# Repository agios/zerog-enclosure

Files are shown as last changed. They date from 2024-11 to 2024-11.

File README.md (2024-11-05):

# Parametric OpenSCAD enclosure for ZeroG Mercury One.1

<div align="center">
  <a href="https://github.com/agios/zerog-enclosure">
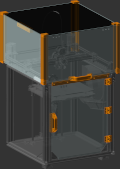
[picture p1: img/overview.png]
    
  </a>
</div>

The purpose was to have a simple design, needing no additional extrusions, only printed parts and acrylic or aluminium composite panels. 
Also, the top had to be easily removable, with convenient front access, and every cover ideally should be unfastened by means of clips, to allow for quick modifications and tweaks.
The sides are held together by mounts where the panels can slide under and any clip you prefer, used this personally [Voron 2.4 Filament Latch](https://www.printables.com/model/172368-voron-24-filament-latch-or-any-2020-extrusion)

The files are parametric, you can tweak to your particular size and thickness. The generated STL and DXF files are for a standard Ender 5, with 4mm panel/acrylic thickness.

You can tweak config.scad to your own dimensions. STL files can be generated using OpenSCAD. The DXF files were generated by exporting the SVG of the projections using OpenSCAD, then converting to DXF in Inkscape, as the OpenSCAD DXF output did not work well for me.

These are pictures of the finished enclosure:

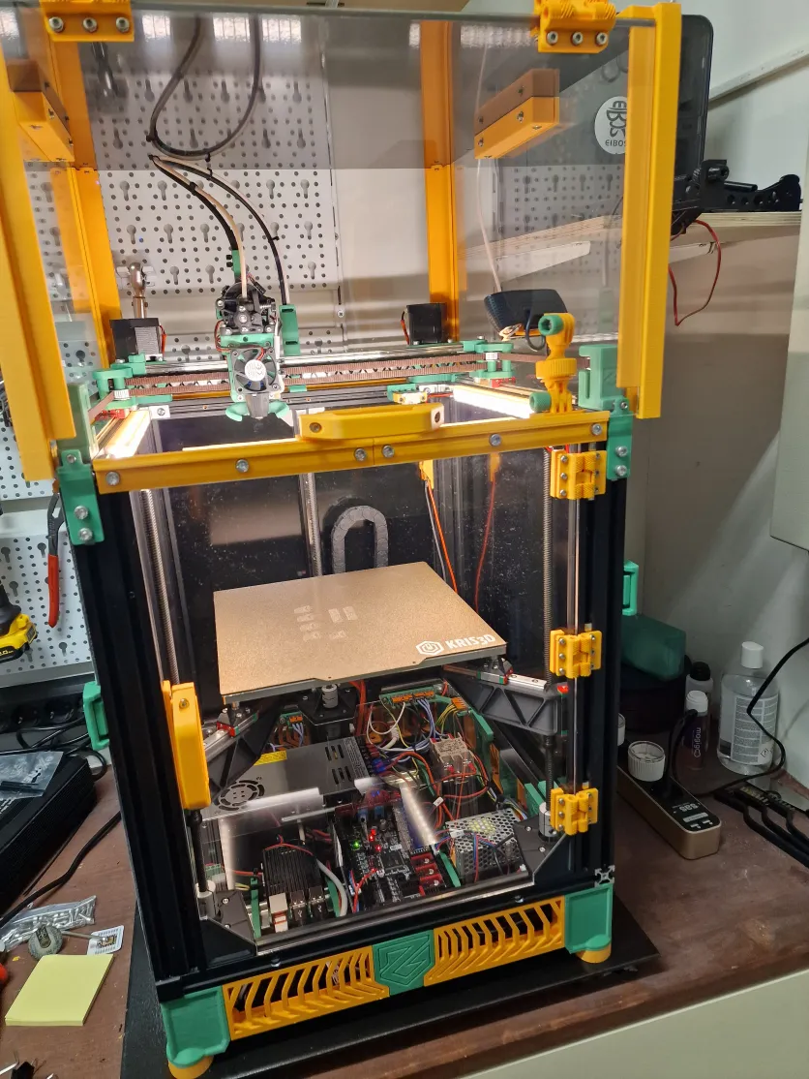
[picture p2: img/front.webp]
Front view

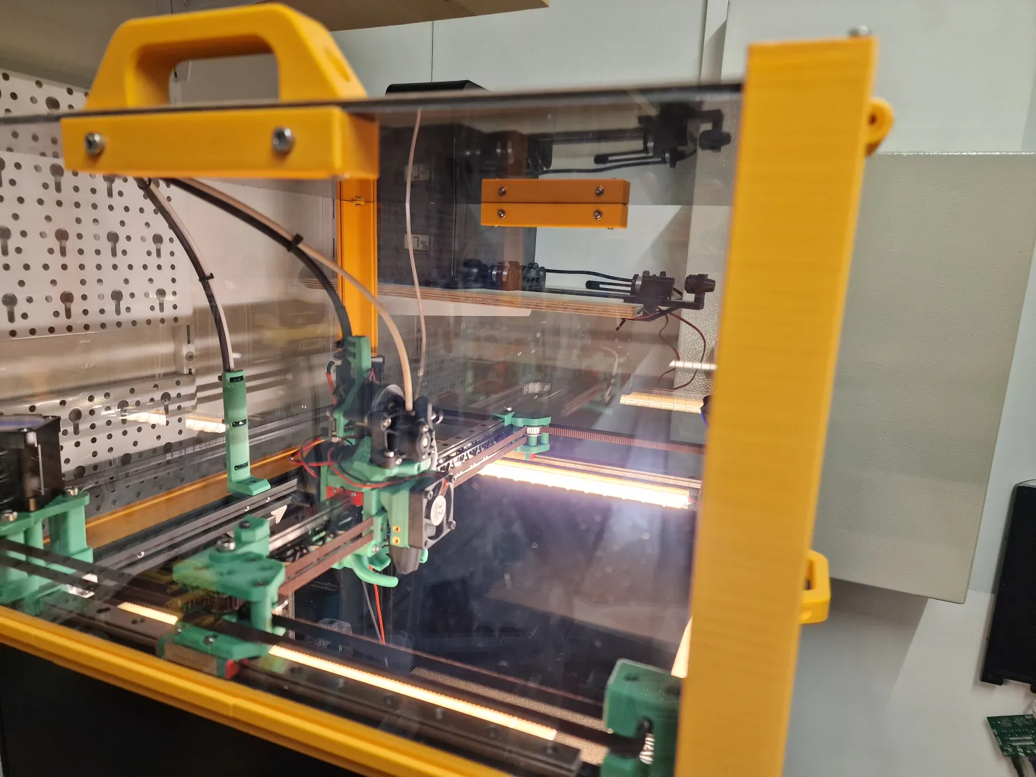
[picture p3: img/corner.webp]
Corner view

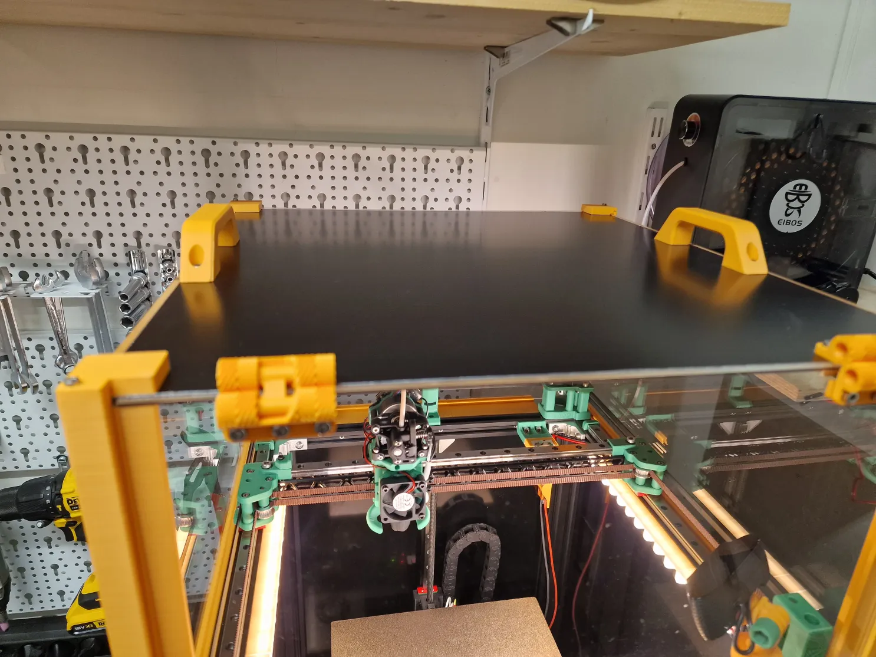
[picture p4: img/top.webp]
Top view

Side view
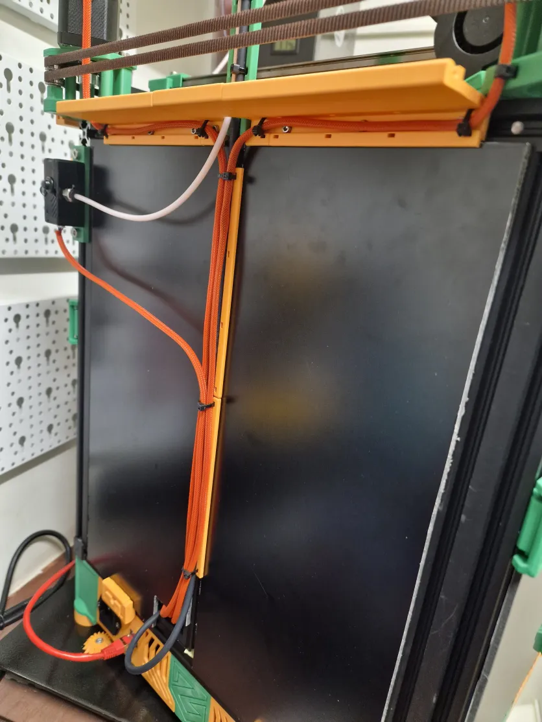
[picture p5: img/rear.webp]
Rear view

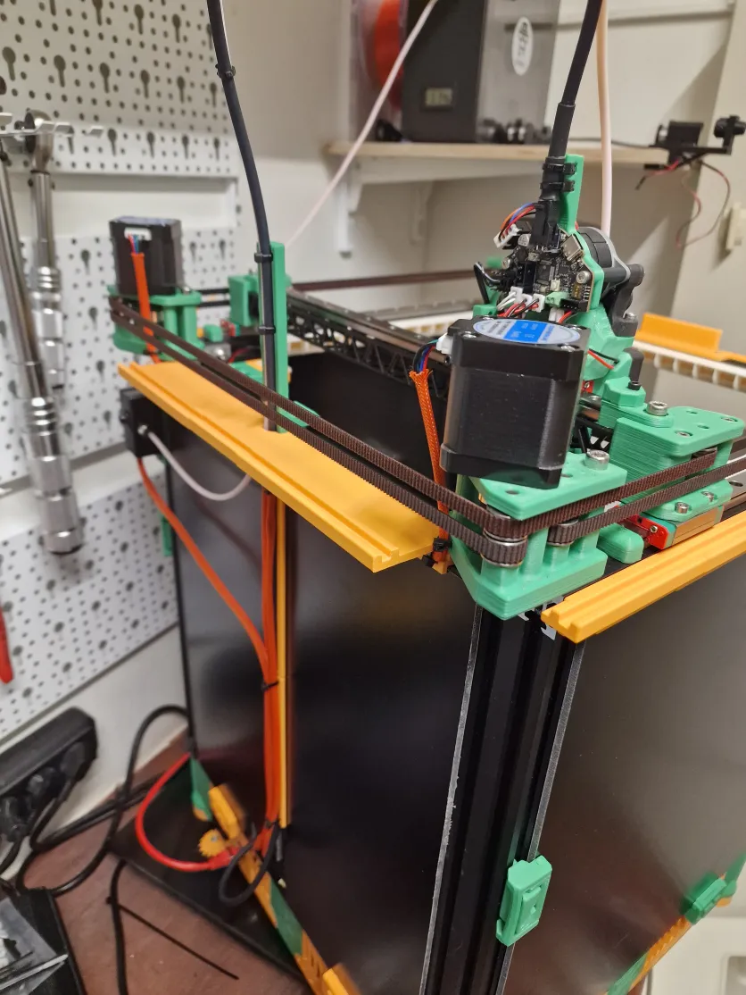
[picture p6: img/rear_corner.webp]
Rear corner view


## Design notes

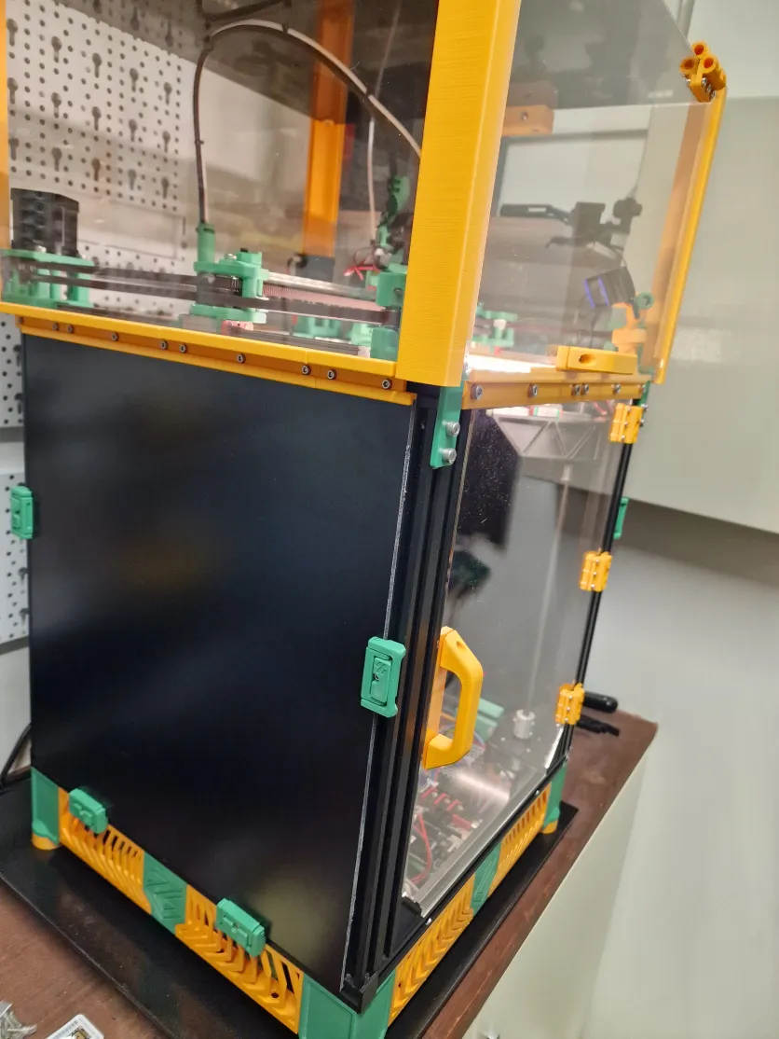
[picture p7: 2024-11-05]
img/side.webp

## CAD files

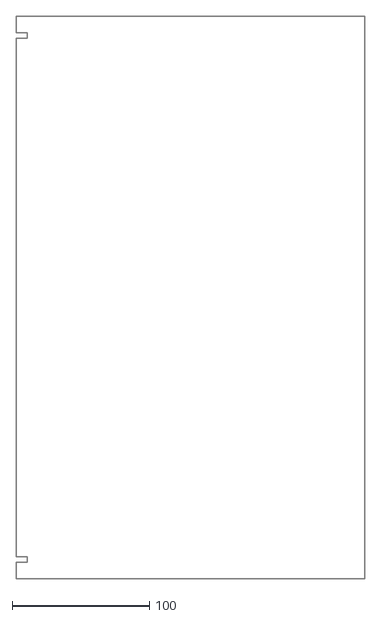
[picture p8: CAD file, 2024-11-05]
DXF/cover_rear.dxf
254.3 x 410.0

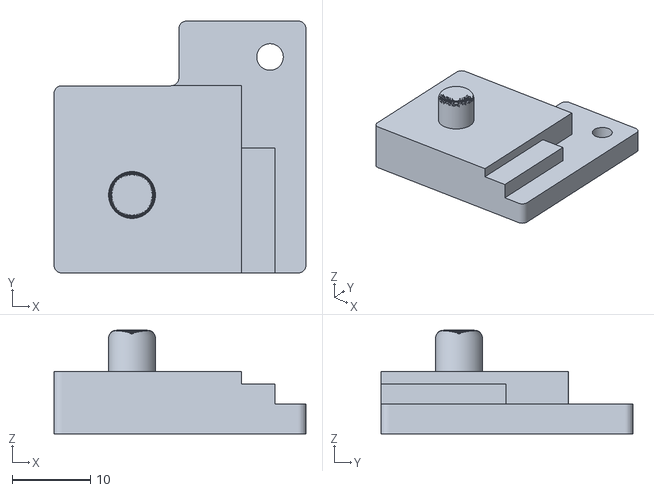
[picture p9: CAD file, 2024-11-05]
SCAD/top/front_right_corner_cover_w_notch.stl
32.3 x 32.3 x 13.3

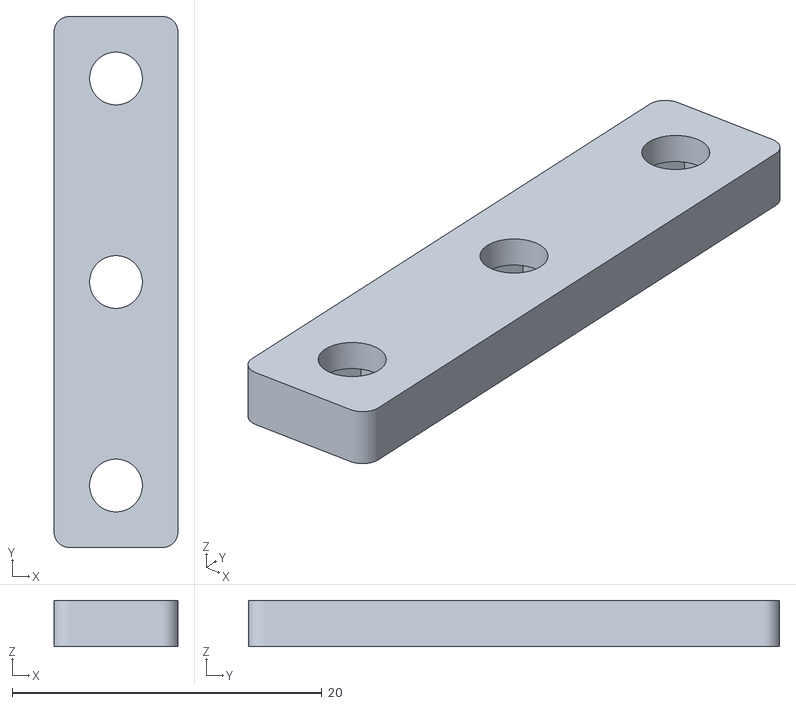
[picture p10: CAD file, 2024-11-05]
STL/bottom/super_mini_hinge_back.stl
8.00 x 34.3 x 3.00

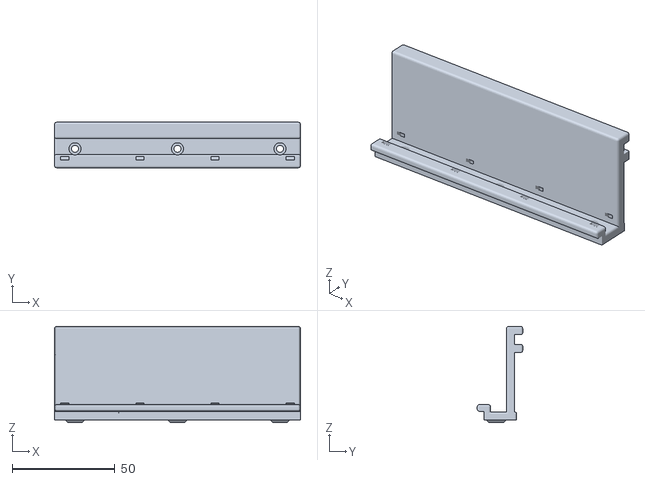
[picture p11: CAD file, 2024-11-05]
STL/mount/rear_top_120.stl
120.0 x 22.2 x 46.9

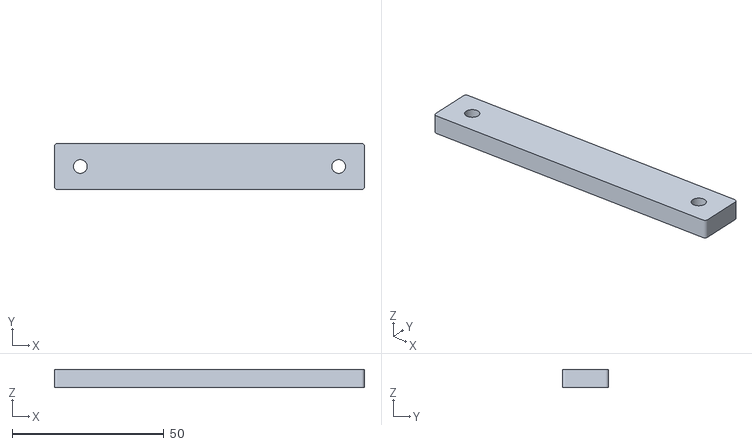
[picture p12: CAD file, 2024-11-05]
STL/top/door_handle_back.stl
102.0 x 15.3 x 6.00

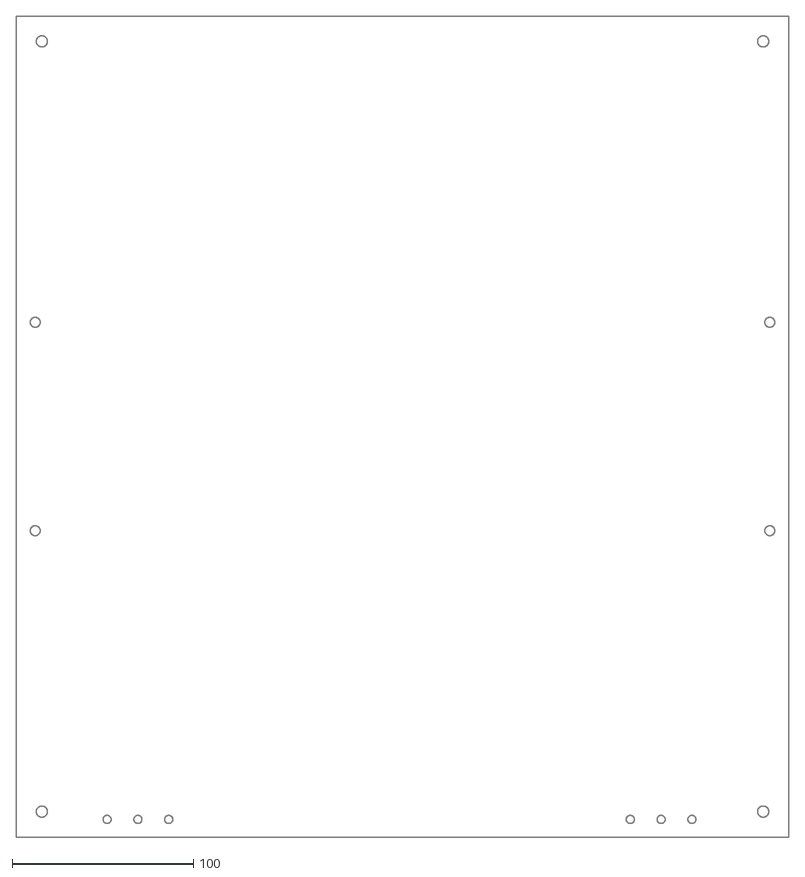
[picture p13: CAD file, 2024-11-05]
DXF/cover_top.dxf
426.0 x 453.0

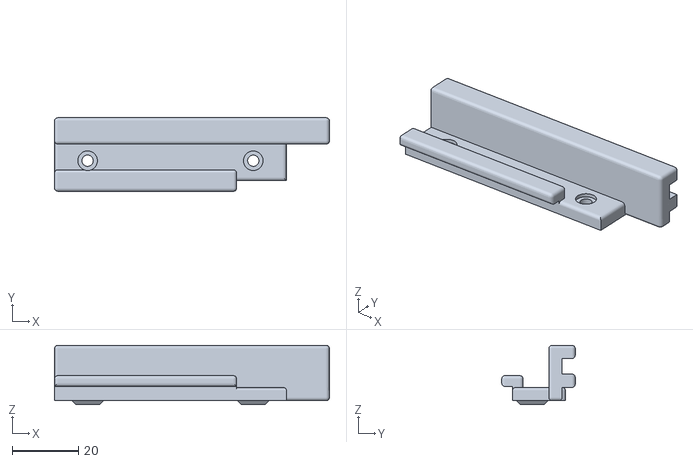
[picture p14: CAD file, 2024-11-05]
STL/mount/side_rear_right.stl
83.0 x 22.2 x 17.9

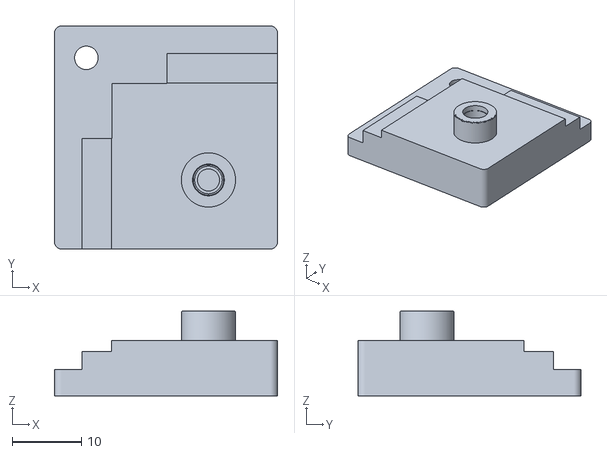
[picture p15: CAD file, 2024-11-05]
STL/top/corner_cover_w_notch.stl
32.3 x 32.3 x 12.3

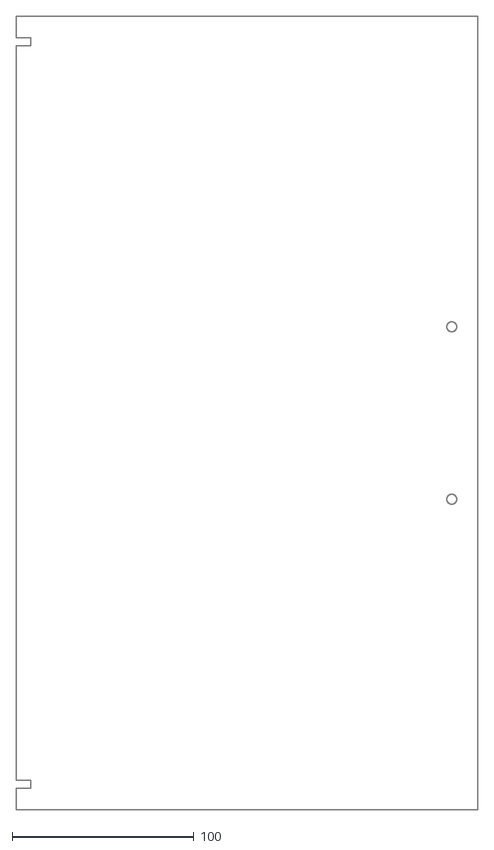
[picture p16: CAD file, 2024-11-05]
DXF/cover_side_x2.dxf
254.3 x 437.0

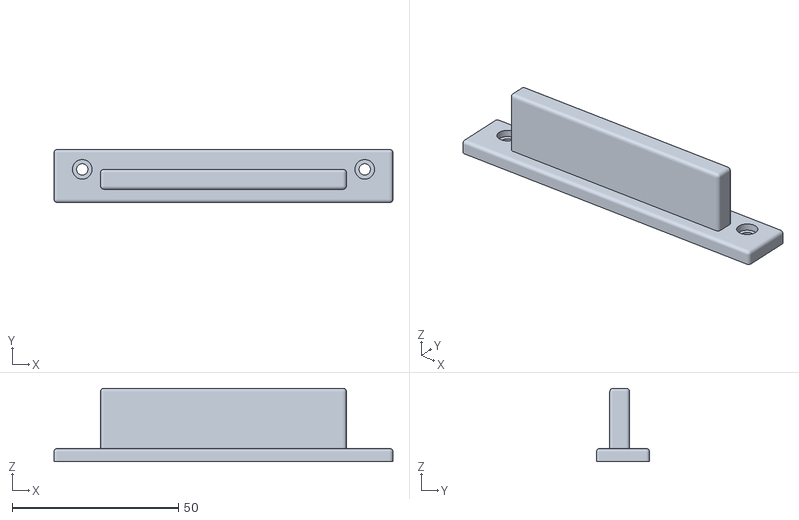
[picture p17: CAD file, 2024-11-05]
STL/bottom/door_stop.stl
102.0 x 16.0 x 22.1

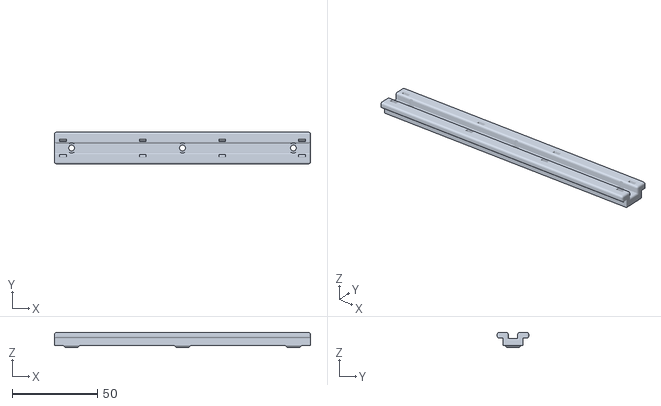
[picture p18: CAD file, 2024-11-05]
STL/mount/rear_center_150.stl
150.0 x 18.5 x 8.76

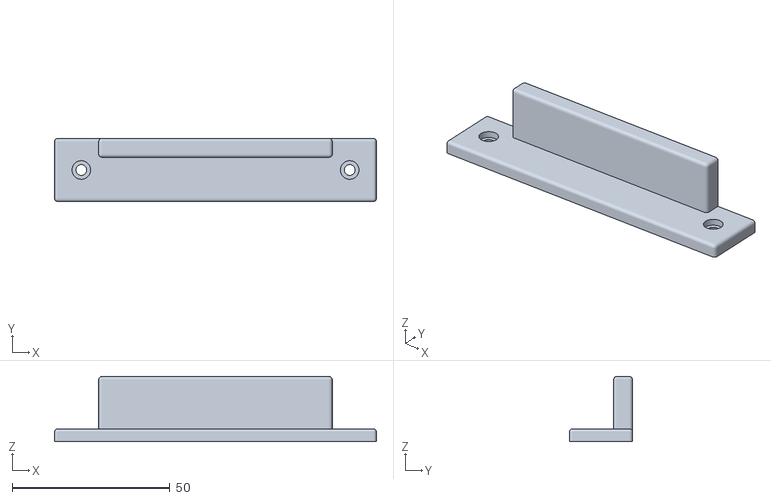
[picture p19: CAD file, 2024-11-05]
STL/top/door_stop.stl
102.0 x 20.0 x 20.6

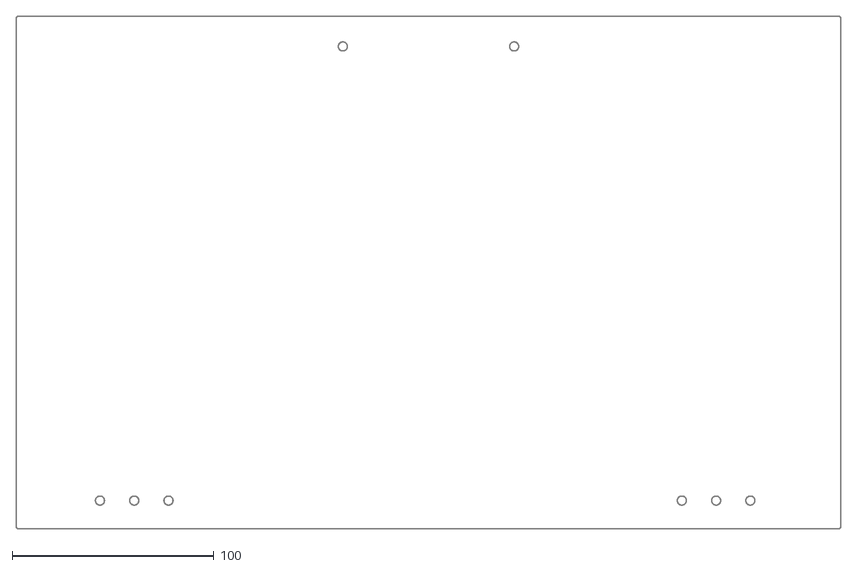
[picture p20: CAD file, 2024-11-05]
DXF/cover_front.dxf
409.0 x 254.3

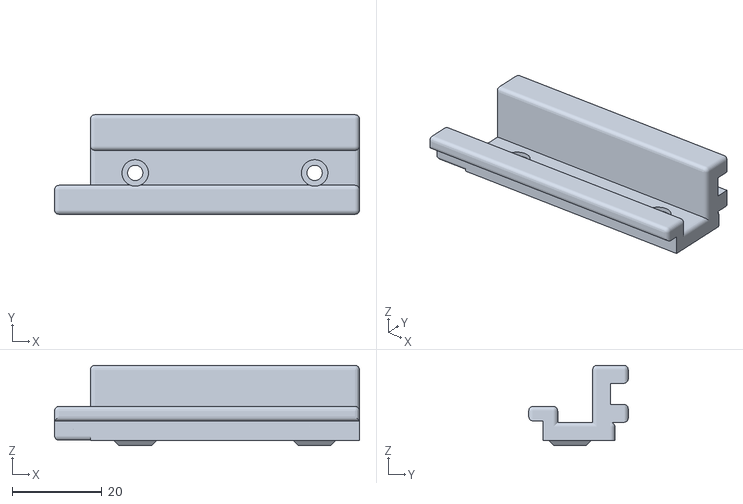
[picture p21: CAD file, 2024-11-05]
STL/mount/side_front_right.stl
68.0 x 22.2 x 17.9

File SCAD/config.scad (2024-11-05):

$fa = $preview ? 9 : 1;
$fs = $preview ? 1 : 0.1;

// Strength
mount_thickness = 4;        // Overall wall thickness
mount_chamfer = 1;          // Radius of chamfers
bottom_ledge_thickness = 3; // Thickness of ledge that anchors lower panels

// Panels
panel_thickness = 4.3;    // Panel thickness + clearance, 4.3 worked well for 4mm aluminum composite panels
panel_ledge_slop = 0.4;   // Amount of overlap of clipped on panels with extrusions, mounts need to be shorter by this much 
panel_front_distance = 6; // Clearance of panel from machine front
panel_side_distance = 8;  // Clearance of panels from machine sides
panel_rear_distance = 37; // Clearance of panel from machine rear

// Top cover
corner_size = 20;         // Size of top cover corner attachement pieces 
top_height = 250;         // Height of top cover

// Frame dimensions
frame_width = 410;
frame_depth = 410;
frame_height = 440;
extrusion_size = 20;

// Door
door_clearance = 2;
door_w = frame_width - 4 * extrusion_size - door_clearance;
door_h = frame_height - 2 * extrusion_size - door_clearance;
door_handle_d = 13;

// Top handle
large_handle_length = 138;
large_handle_width = 20.7;
large_handle_hole_d = 115;

// Door handle
small_handle_length = 102;
small_handle_width = 15.3;
small_handle_hole_d = 85;

// Hinges
mini_hinge_d = 17;
super_mini_hinge_d = 13.13;

// Panel cutting calculations
// top_side = y_machine_width(410) + panel_rear_distance + panel_front_distance - 4 * mount_thickness;
//          = 436
// top_rear = x_machine_width(410) + 2 * panel_side_distance - 4 * mount_thickness;
//          = 410
// top_depth = y_machine_width(410) + panel_rear_distance + panel_front_distance;
//           = 453 / 445
// top_width = x_machine_width + 2 * panel_side_distance;
//           = 418

// Various
tiny = 0.005; // tiny value is used to stop artifacts from planes lining up perfectly

module plastic() {
  color("DarkOrange", 0.7) children();
}

module acrylic() {
  %color("LightCyan", 0.5) children();
  // %color([0.5, 0.5, 0.5, 0.5]) children();
}

module composite() {
  %color("Black", 0.8) children();
}

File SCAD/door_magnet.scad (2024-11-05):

use <lib/Round-Anything/polyround.scad>
include <lib/helpers.scad>
include <lib/BOSL2/std.scad>
include <lib/BOSL2/screws.scad>

magnets = 3;
door_magnet_positions = [20:(small_handle_length-40)/(magnets - 1):small_handle_length-20];

module door_handle_back(thickness = 6) {
    difference() {
        polyRoundExtrude(
            [
                [0, 0, 1],
                [0, small_handle_length, 1],
                [small_handle_width, small_handle_length, 1],
                [small_handle_width, 0, 1],
            ],
            thickness,
            0,
            0
        );
        for(i=[
            [small_handle_width / 2, 8.5],
            [small_handle_width / 2, small_handle_length - 8.5],
        ]) translate([i.x, i.y, -tiny]) union() {
            nut_trap_inline(3, "M4", $slop=0.1);
            screw_hole("M4,10", anchor=BOTTOM);
        }
        for(y=door_magnet_positions)
            translate([small_handle_width / 2, y, 0.6])
                cylinder(h=3.2, d=6.1);
    }
}

module door_stop(clearance=0, stop_position=6, offset=5, thickness = 6, screw_support = true) {
    difference() {
        union() {
            // base (screwed to extrusion)
            polyRoundExtrude(
                [
                    [0, 0, 1],
                    [0, small_handle_length, 1],
                    [20 - clearance, small_handle_length, 1],
                    [20 - clearance, 0, 1],
                ],
                mount_thickness,
                mount_chamfer,
                0
            );
            if (screw_support) for(i=[
                [10, 8.5],
                [10, small_handle_length - 8.5],
            ]) translate([i.x, i.y, -tiny])
                screw_support("M3");
            // stop
            translate([20 - clearance - stop_position, 0, 0]) rotate([0, -90, 0]) polyRoundExtrude(
                [
                    [0, 14, 1],
                    [0, small_handle_length - 14, 1],
                    [small_handle_width + offset, small_handle_length - 14, 1],
                    [small_handle_width + offset, 14, 1],
                ],
                thickness,
                mount_chamfer,
                mount_chamfer,
            );
            
        }
        for(i=[
            [10, 8.5],
            [10, small_handle_length - 8.5],
        ]) translate([i.x, i.y, -tiny])
            screw_hole("M3,2", head="socket", anchor=BOTTOM);
        for(y=door_magnet_positions) {
            translate([20 - clearance - stop_position - 3.2 - 0.6, y, offset + small_handle_width / 2]) rotate([0, 90, 0])
                cylinder(h=3.2, d=6.2);
            translate([20 - clearance - stop_position - 0.6, y - 3.1, -tiny]) rotate([0, -90, 0])
                cube([ offset + small_handle_width / 2 + tiny, 6.2, 3.2]);
        }
    }
}

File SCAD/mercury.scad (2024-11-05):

color("DimGray") 
union() {
  difference() {
    import("lib/mercury_235_assembly.stl", convexity=80);
    // translate([-150, -160, -20]) cube([300, 351.8, 400]);
    // translate([-150, 130, -20]) cube([300, 61.8, 470]);
  };
  translate([0, 6.85, 27.5]) 
  import("lib/Hydra_5pro.stl", convexity=20);
}

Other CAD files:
STL/bottom/door_handle_back.stl
STL/top/mini_hinge_back.stl
DXF/door.dxf
STL/mount/side_rear_left.stl
SCAD/overview.scad
SCAD/bottom/door.scad
SCAD/bottom/door_handle.scad
SCAD/bottom/door_handle_back.scad
SCAD/bottom/door_projection.scad
SCAD/bottom/door_stop.scad
SCAD/bottom/handle_back_magnet.scad
SCAD/bottom/super_mini_hinge_back.scad
SCAD/mount/front_184.scad
SCAD/mount/front_face_corner.scad
SCAD/mount/front_magnet.scad
SCAD/mount/ledge.scad
SCAD/mount/mount.scad
SCAD/mount/rear_center_150.scad
SCAD/mount/rear_center_80.scad
SCAD/mount/rear_top_120.scad
SCAD/mount/rear_top_center.scad
SCAD/mount/side_130.scad
SCAD/mount/side_50.scad
SCAD/mount/side_front_left.scad
SCAD/mount/side_front_right.scad
SCAD/mount/side_rear_left.scad
SCAD/mount/side_rear_right.scad
SCAD/relay_mount.scad
SCAD/top/corner.scad
SCAD/top/corner_cover_flange.scad
SCAD/top/corner_cover_w_notch.scad
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
